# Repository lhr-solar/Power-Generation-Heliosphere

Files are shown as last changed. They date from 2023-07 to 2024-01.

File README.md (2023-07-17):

# :sunny: Heliosphere - Lighting automation control jig.

- [:sunny: Heliosphere - Lighting automation control jig.](#sunny-heliosphere---lighting-automation-control-jig)
  - [Repository Structure](#repository-structure)
  - [Maintainers](#maintainers)
  - [Versioning](#versioning)
  - [TODO](#todo)
    - [Documentation](#documentation)
    - [HW](#hw)
    - [SW](#sw)

---

## Repository Structure

- **datasheets** - contains datasheets for major components of the PCB.
- **docs** - contains documentation on how to build, test, and use the PCB.
- **fw** - contains fw that is loaded onto the PCB.
  - **tests** - test programs used to characterize and validate the PCB.
  - **src** - main program used to run the PCB.
  - **inc** - internally developed libraries specific for the PCB.
  - **lib** - third party libraries used by the PCB.
- **hw**
  - **footprints** - project specfic footprint association files for the PCB.
  - **models** - 3d .step files for the PCB 3d viewer.
  - **symbols** - project specific symbol files for the PCB.
  - **vX.Y.Z** - frozen versioning folder for PCB production files.
  - design files

---

## Maintainers

The current maintainer of this project is Matthew Yu as of 07/16/2023. His email
is [matthewjkyu@gmail.com](matthewjkyu@gmail.com).

Special thanks to Professor Gary Hallock, who supervised the development and
design of this project.

---

## Versioning

This PCB is on unified version `0.1.0`. Every time the schematic and/or layout
is updated, this version number should go up. We use [semantic
versioning](https://semver.org/) to denote between versions. See the
[changelog](./docs/CHANGELOG.md) for more details.

---

## TODO

### Documentation

- Update the following documents:
  - [Ordering and assembly](./docs/ORDERING_AND_ASSEMBLY.md)
  - [Testing](./docs/TESTING.md)
- Add datasheets for key components of the device.

### HW

- See [changelog 0.2.0rc](./docs/CHANGELOG.md#020rc-proposed) proposed changes to improve board cost, size.

### SW

- Regenerate code for MBED with proposed file structure.

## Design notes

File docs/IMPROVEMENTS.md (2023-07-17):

# IMPROVEMENTS

- [IMPROVEMENTS](#improvements)
  - [Digital PWM control](#digital-pwm-control)

---

## Digital PWM control

After verifying that v0.1.0 works with analog trimpots, the next step would be
using a digital PWM controller to control brightness. This is useful in a couple
ways:

- Removes dependency on Dale trimpots, which don't appear to exist anymore
  outside of Hallock's lab
- The trimpots are large, which restricts the lighting density and therefore the
  maximum uniform irradiance incident upon the surface (e.g. farther the
  spacing, the more vertical distance required for even spread). Switching to a
  SOT-23-3 or similar package MOSFET hooked up to a controller reduces the size
  restriction drastically. Ideally we can get back to 40x40 mm instead of 50x50 mm.
- The digital control enables automagic feedback control. Hook up to the PV
  Curve Tracer and the Blackbody B, and then we can automatically tune segment
  brightness as well as emulate various PVEnvironment regimes that are only
  usable in Eclipse simulation.

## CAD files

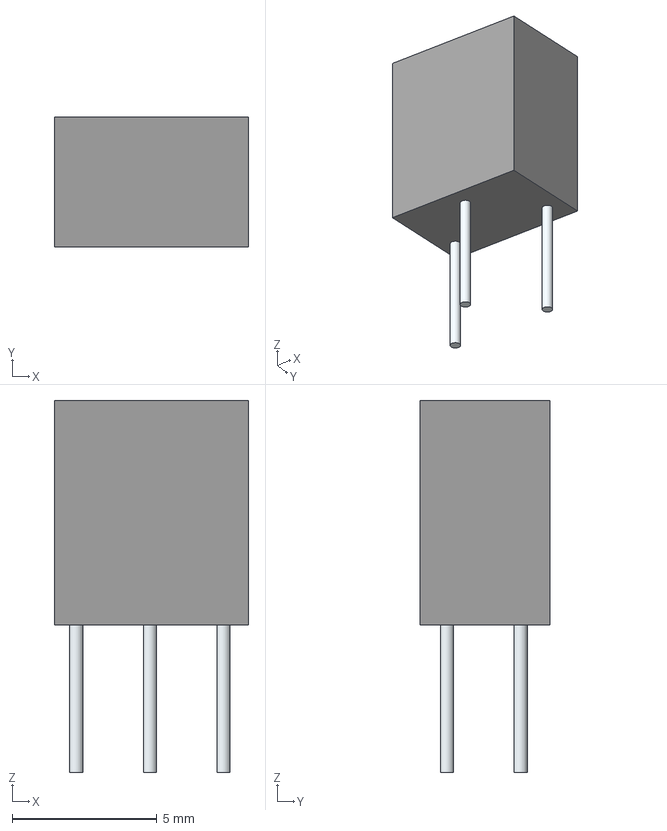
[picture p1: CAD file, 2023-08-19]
hw/models/bourns_3266W_1_200LF.stp
6.71 x 4.50 x 12.8 mm
Leads

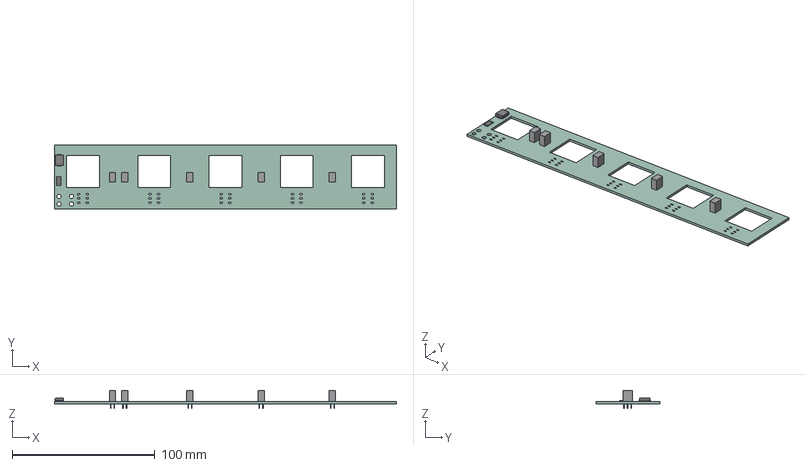
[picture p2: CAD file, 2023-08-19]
hw/v0.1.0/heliosphere.step
240.0 x 45.0 x 12.8 mm
_autosave-heliosphere PCB

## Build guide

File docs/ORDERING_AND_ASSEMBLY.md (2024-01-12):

# ORDERING AND ASSEMBLY

## Ordering

- Generate gerbers using JLC PCB fabrication toolkit (1 button click).
- Navigate to JLCPCB site and upload zip file provided.
- No assembly is performed for this PCB. Order as default FR4, 2 layer.

## Assembly

Use the ibom.html provided in the outputs file for placement.

- Solder R101 to PCB.
  - Solder one side before other. Keep package flat against PCB.
- Solder D106 to PCB.
  - Marking side is the cathode (positive). Solder closest to enclosed line on silkscreen.
  - Solder one side before other. Keep package flat against PCB.
- Solder VR101 - VR105 to PCB.
  - Place on PCB, hold, flip PCB, bend legs outwards to keep in place.
- Solder D101 - D105 to PCB.
  - Tin surfaces of pads, both on PCB and LED package. Keep flat.
  - Use masking tape to hold package to bottom side, facing down. Align with silkscreen.
  - With a soldering iron, solder from top of PCB into holes. Make sure
    soldering tip can reach the package. Hold firm to each other. Fill hole with
    solder. Hold long enough that solder wicks down to PCB pad. A negative
    indent is good.
  - Verify that the pieces are soldered down properly and flush. Gaps require
    resoldering and will likely not light up during testing.
- Solder AWG 18 wires to positive, negative contacts indicated on silkscreen.

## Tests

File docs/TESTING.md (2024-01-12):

# TESTING

1. Ensure that diode is placed correctly using multimeter. Should short from GND to PWR.
2. Use a power supply at >=10V, 0.5A to power the board. LEDs should turn on.
3. Lights should dim or brighten based on turns of trimpots.
   1. Right turns increase resistance. Left turns decrease resistance.
4. Use the Blackbody B to measure the irradiance uniformity of every light in a
   dark room. Place the board while running under the centerpoint of each light.
   Measure the light and adjust the resistance of the trimpot to gradually align
   all measurements to a single value.

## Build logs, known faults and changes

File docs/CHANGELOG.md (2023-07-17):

# CHANGELOG

- [CHANGELOG](#changelog)
  - [0.1.0](#010)
  - [0.2.0rc (proposed)](#020rc-proposed)

---

## 0.1.0

Initial version.

## 0.2.0rc (proposed)

**Schematic**

- Switch from manual analog control via rotary potentiometers to digital control via PWM.

**Layout**

- Optimize layout.

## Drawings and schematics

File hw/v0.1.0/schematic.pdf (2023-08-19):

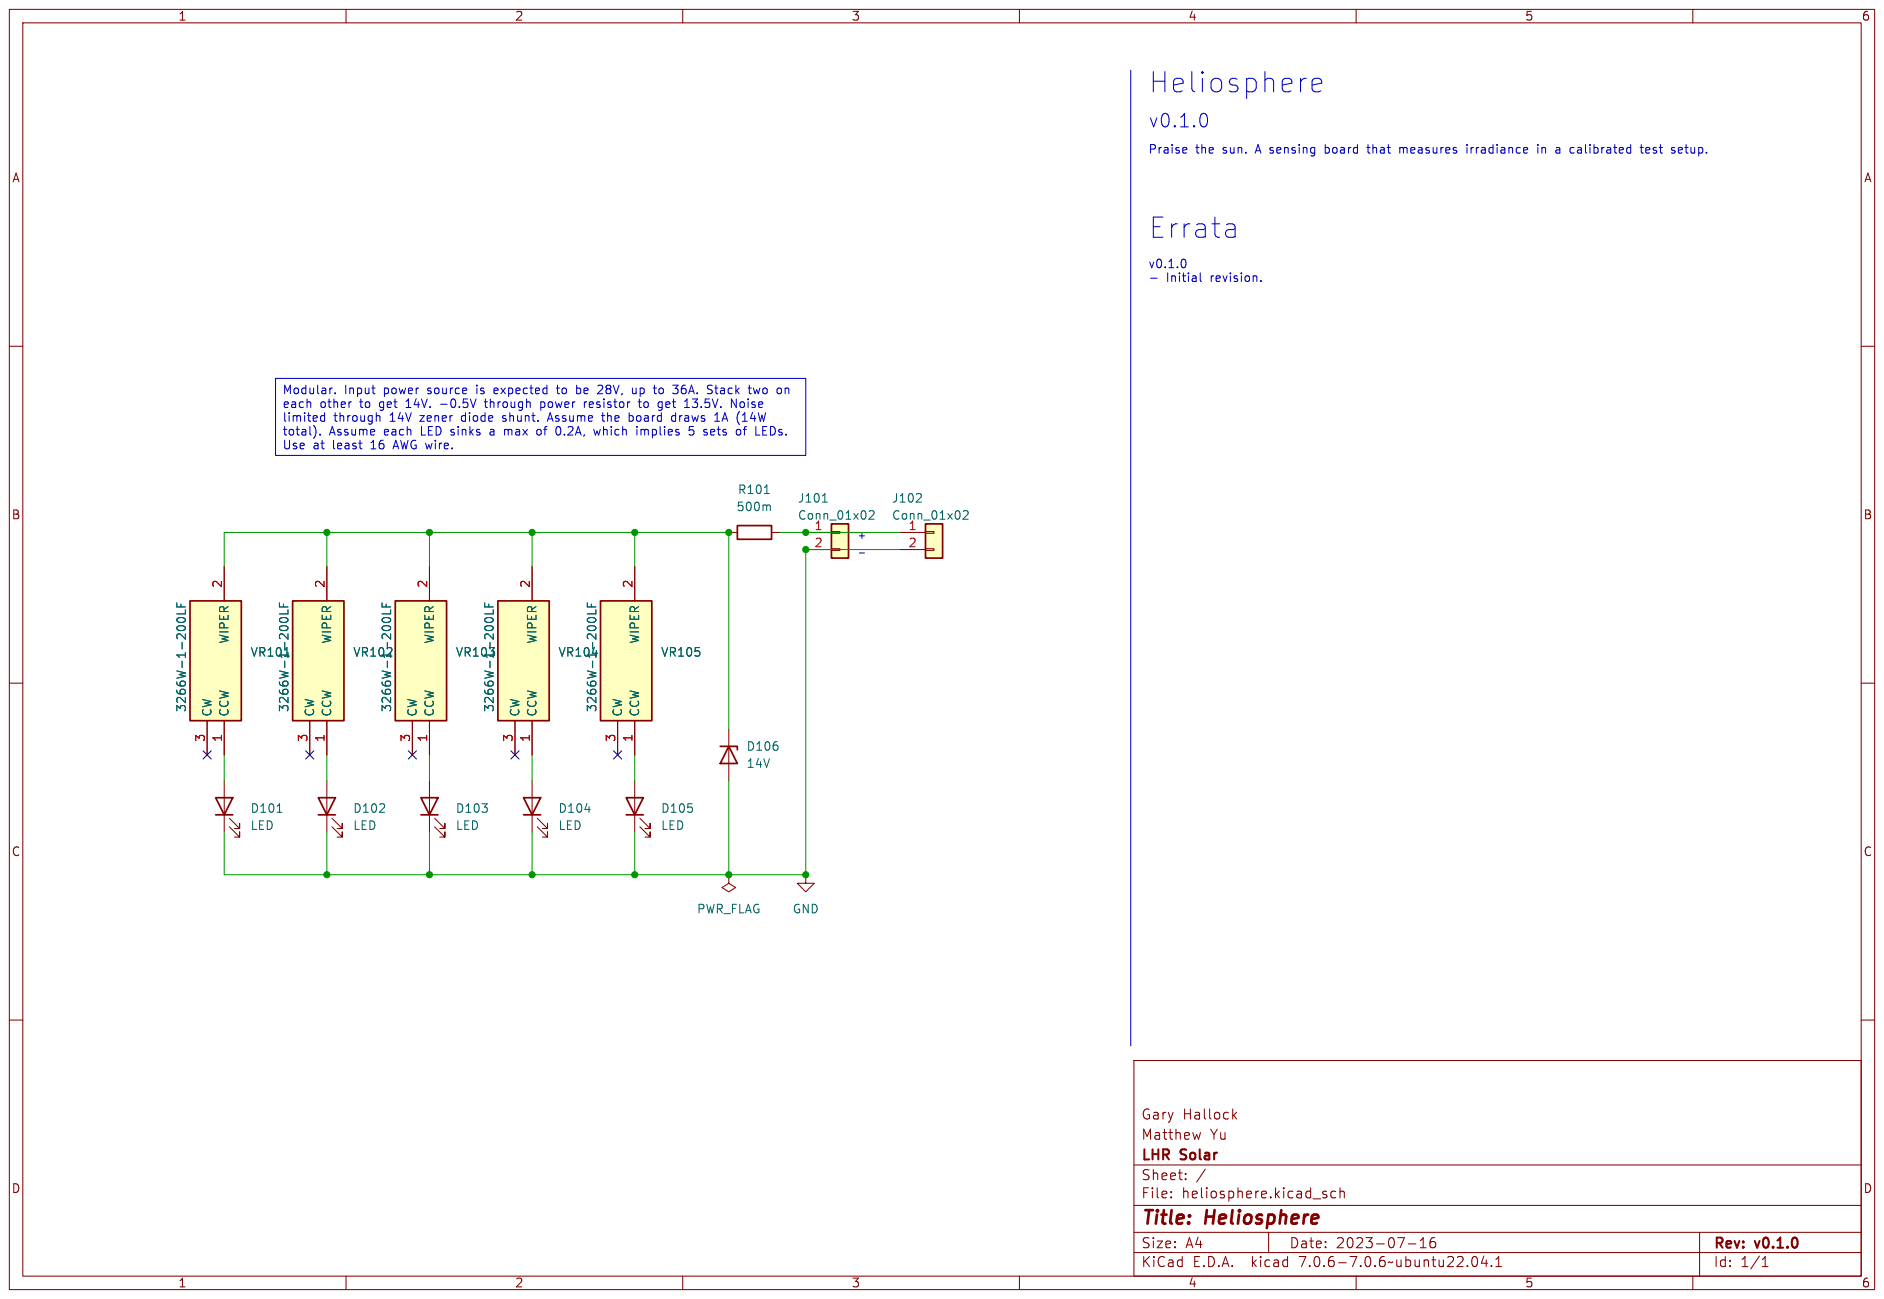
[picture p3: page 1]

Modular. Input power source is expected to be 28V, up to 36A. Stack two on

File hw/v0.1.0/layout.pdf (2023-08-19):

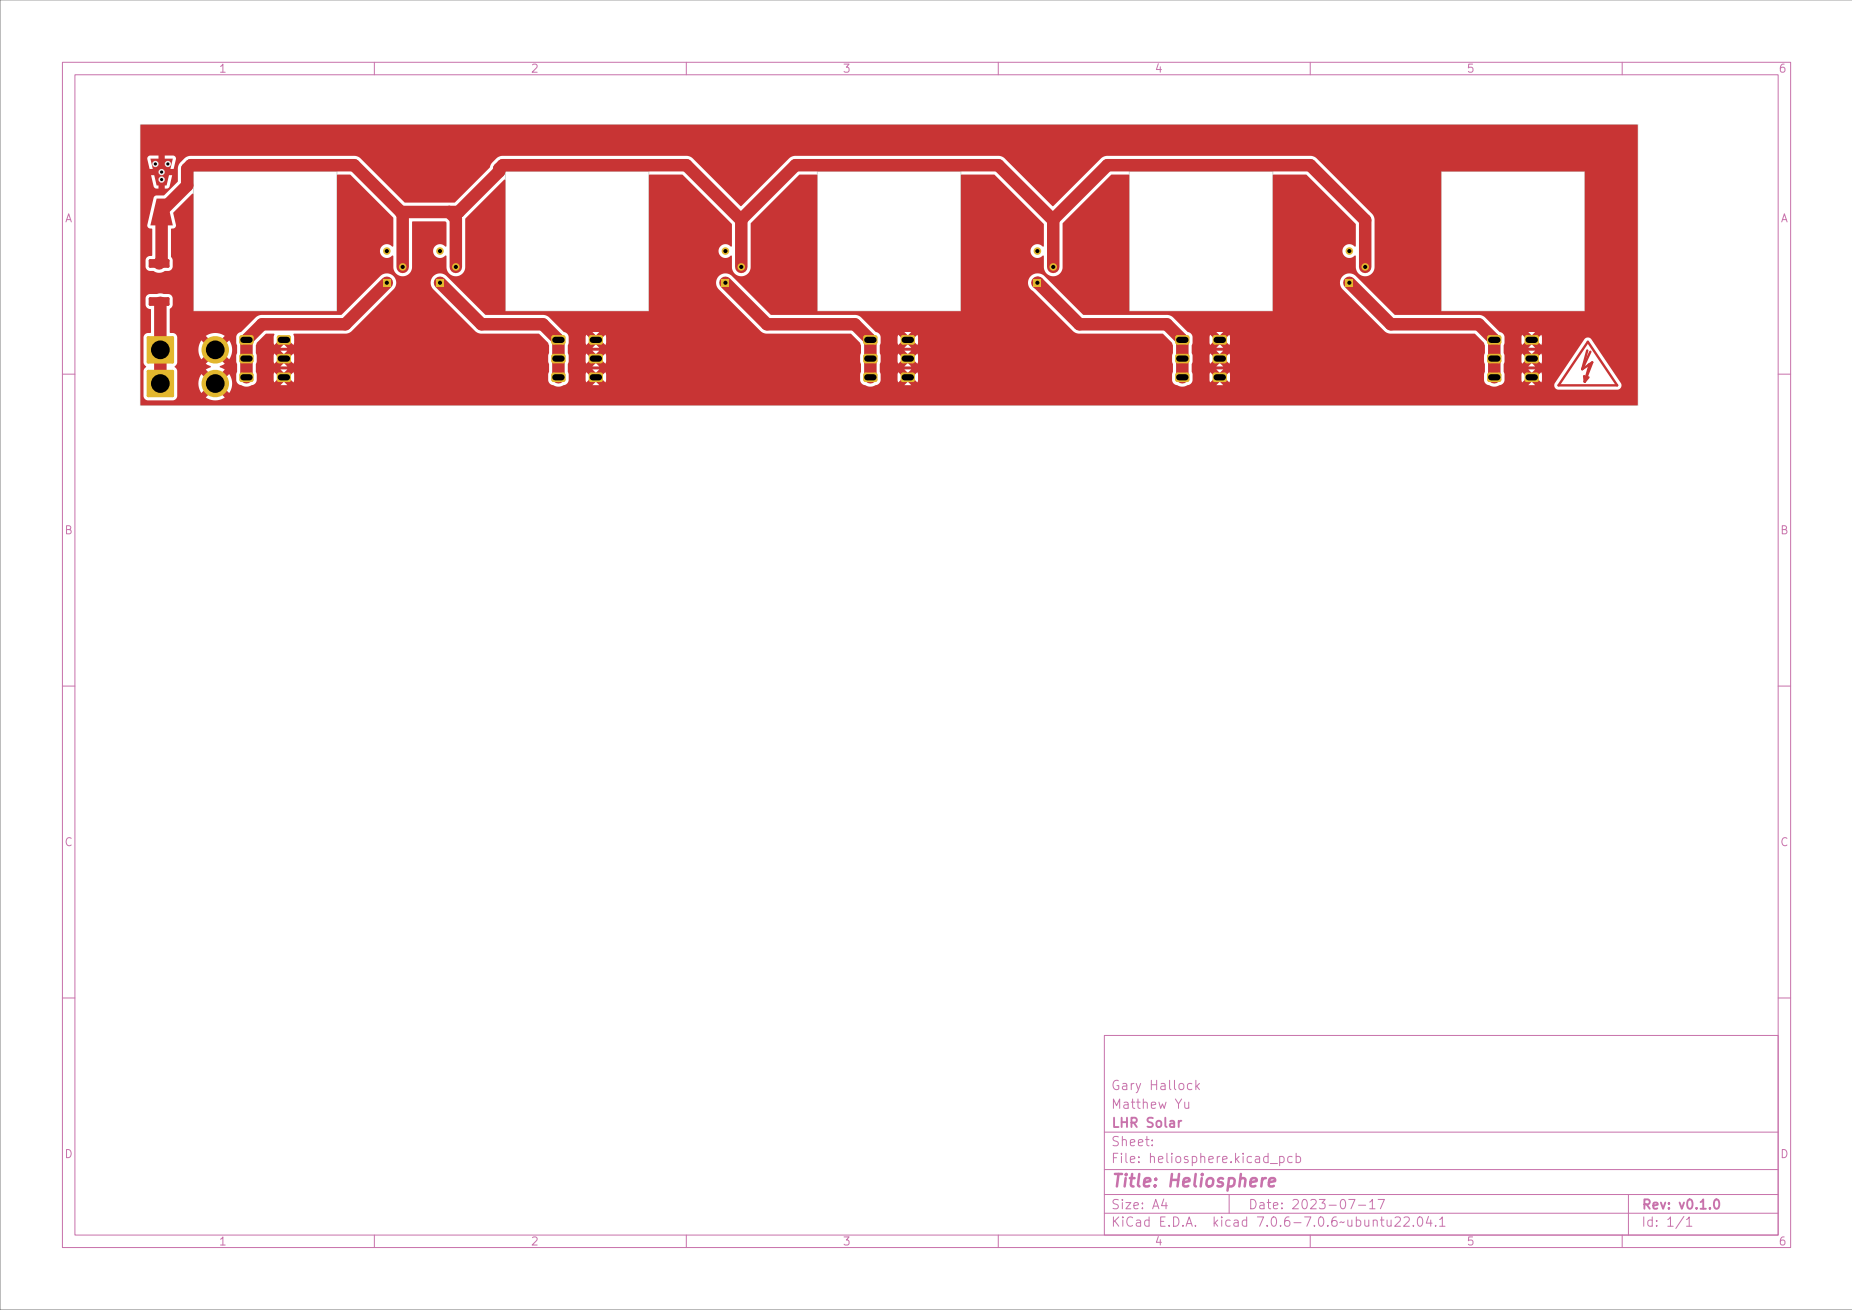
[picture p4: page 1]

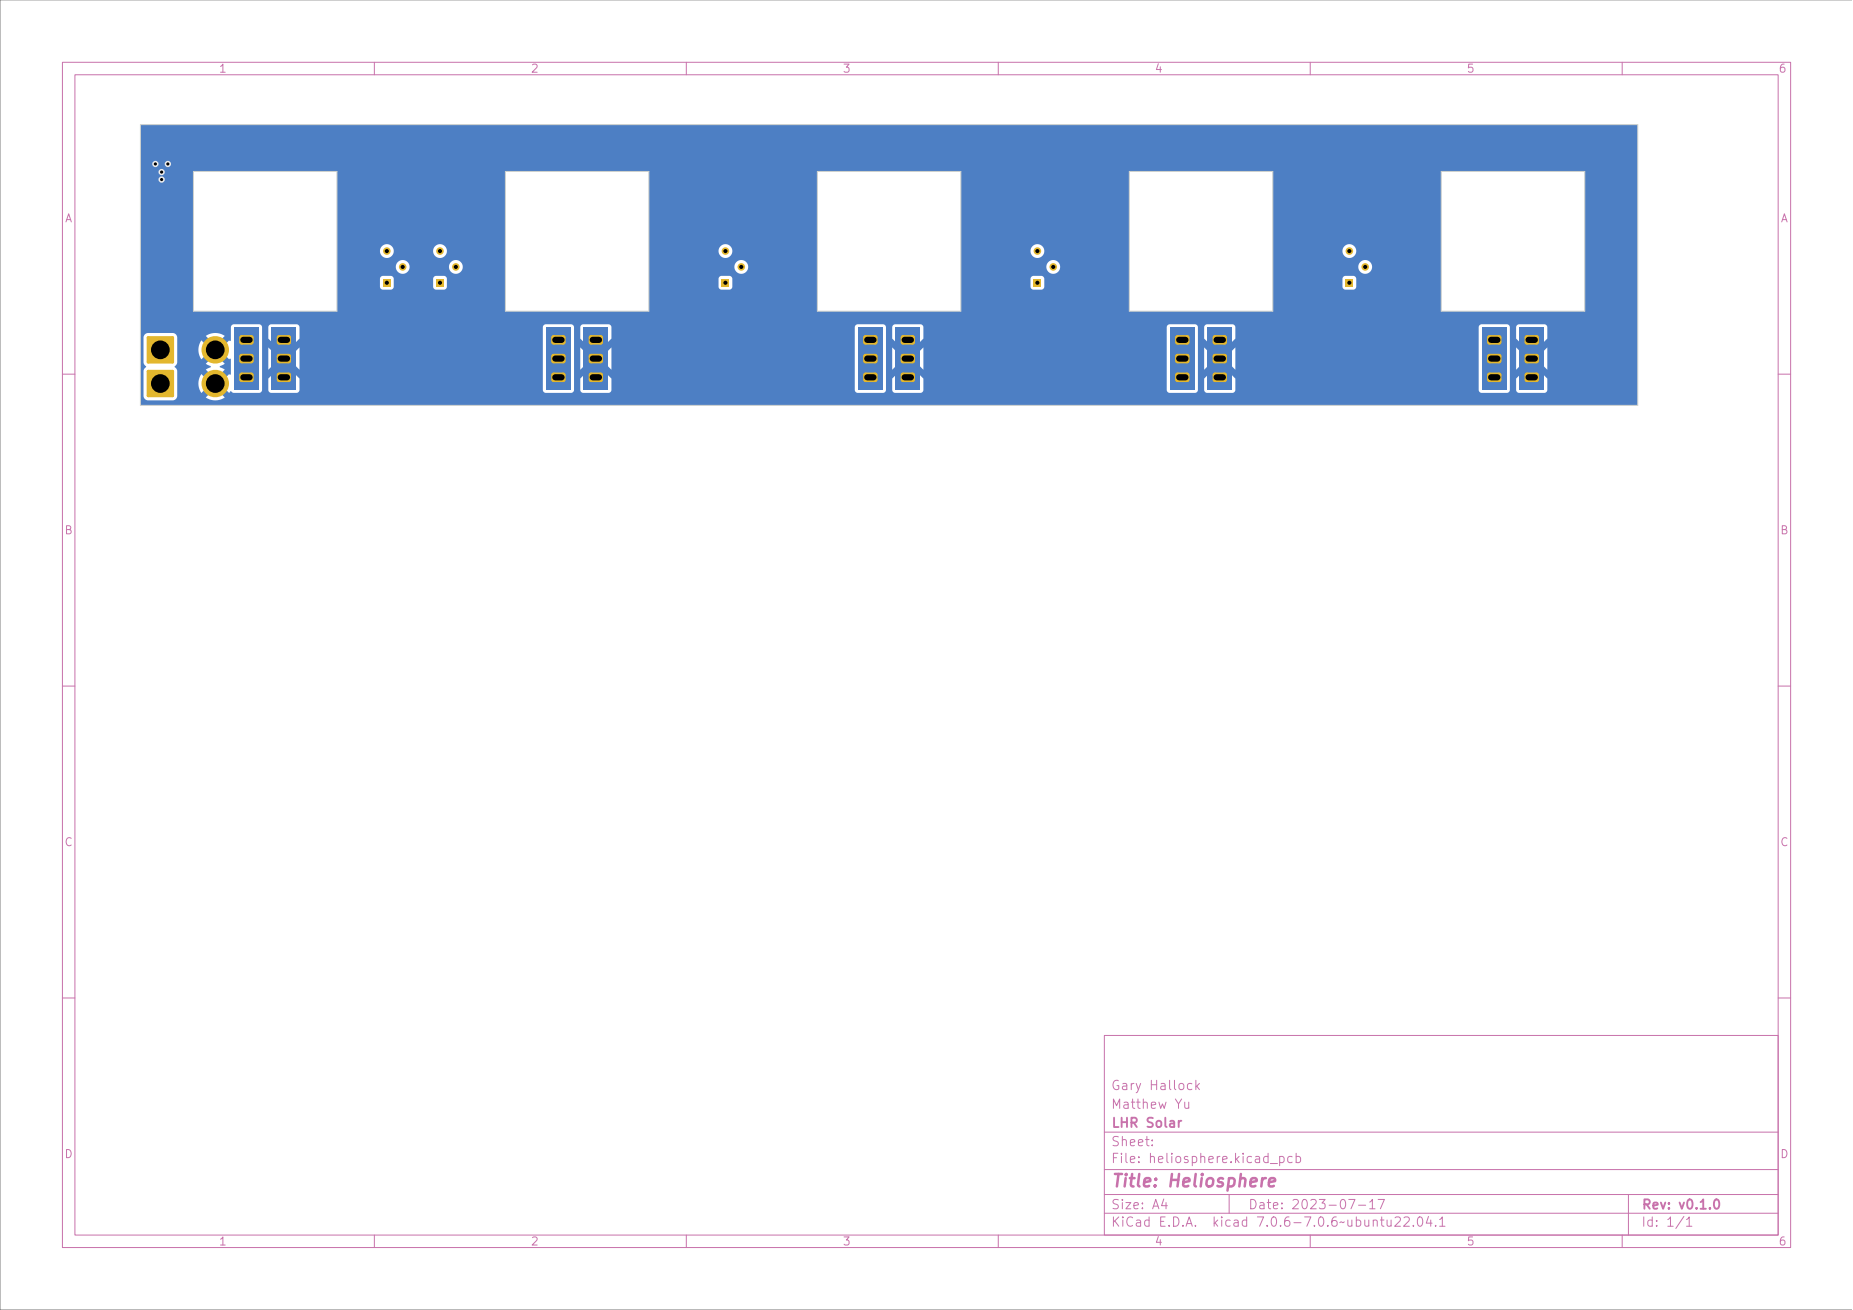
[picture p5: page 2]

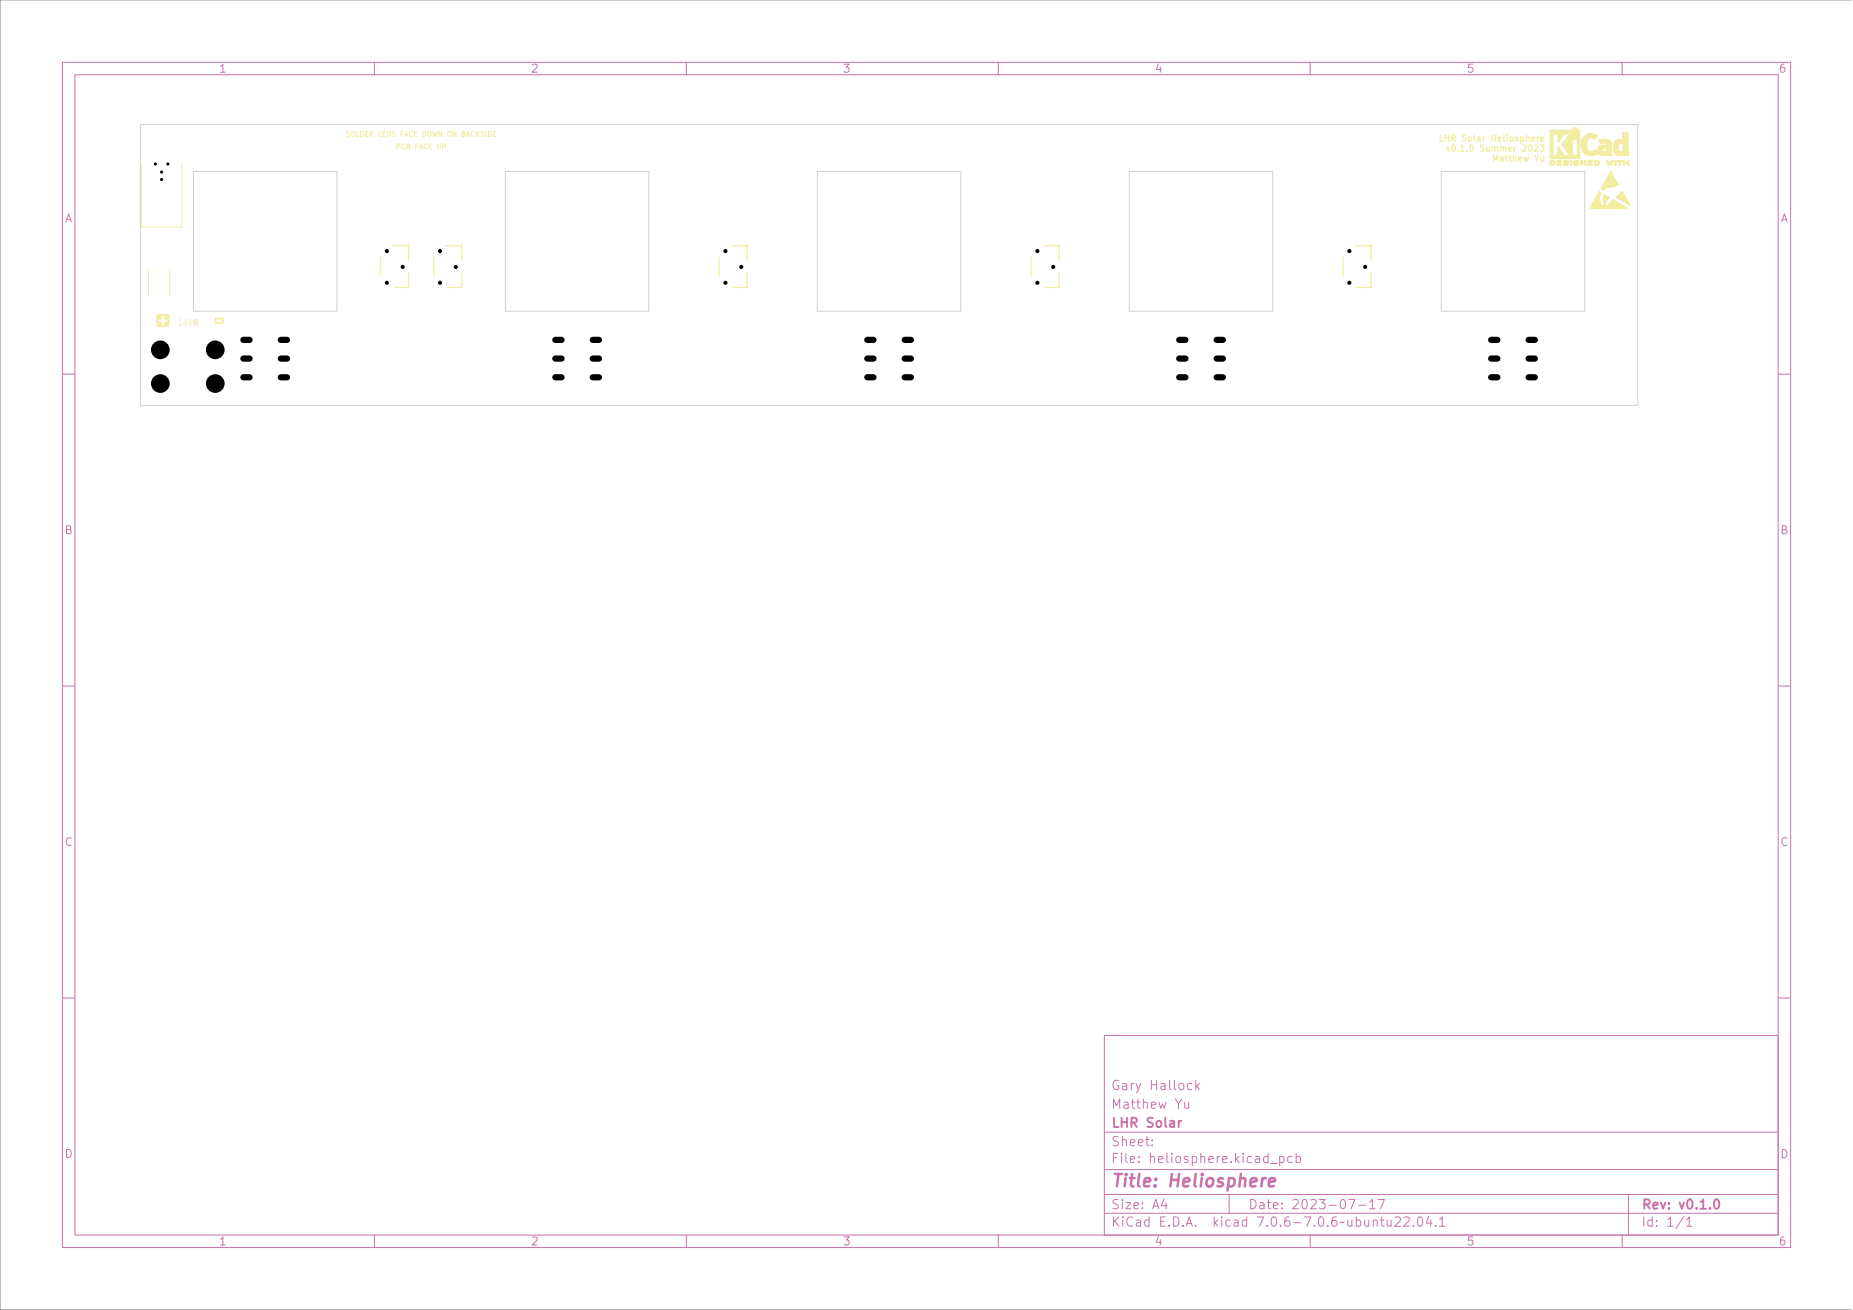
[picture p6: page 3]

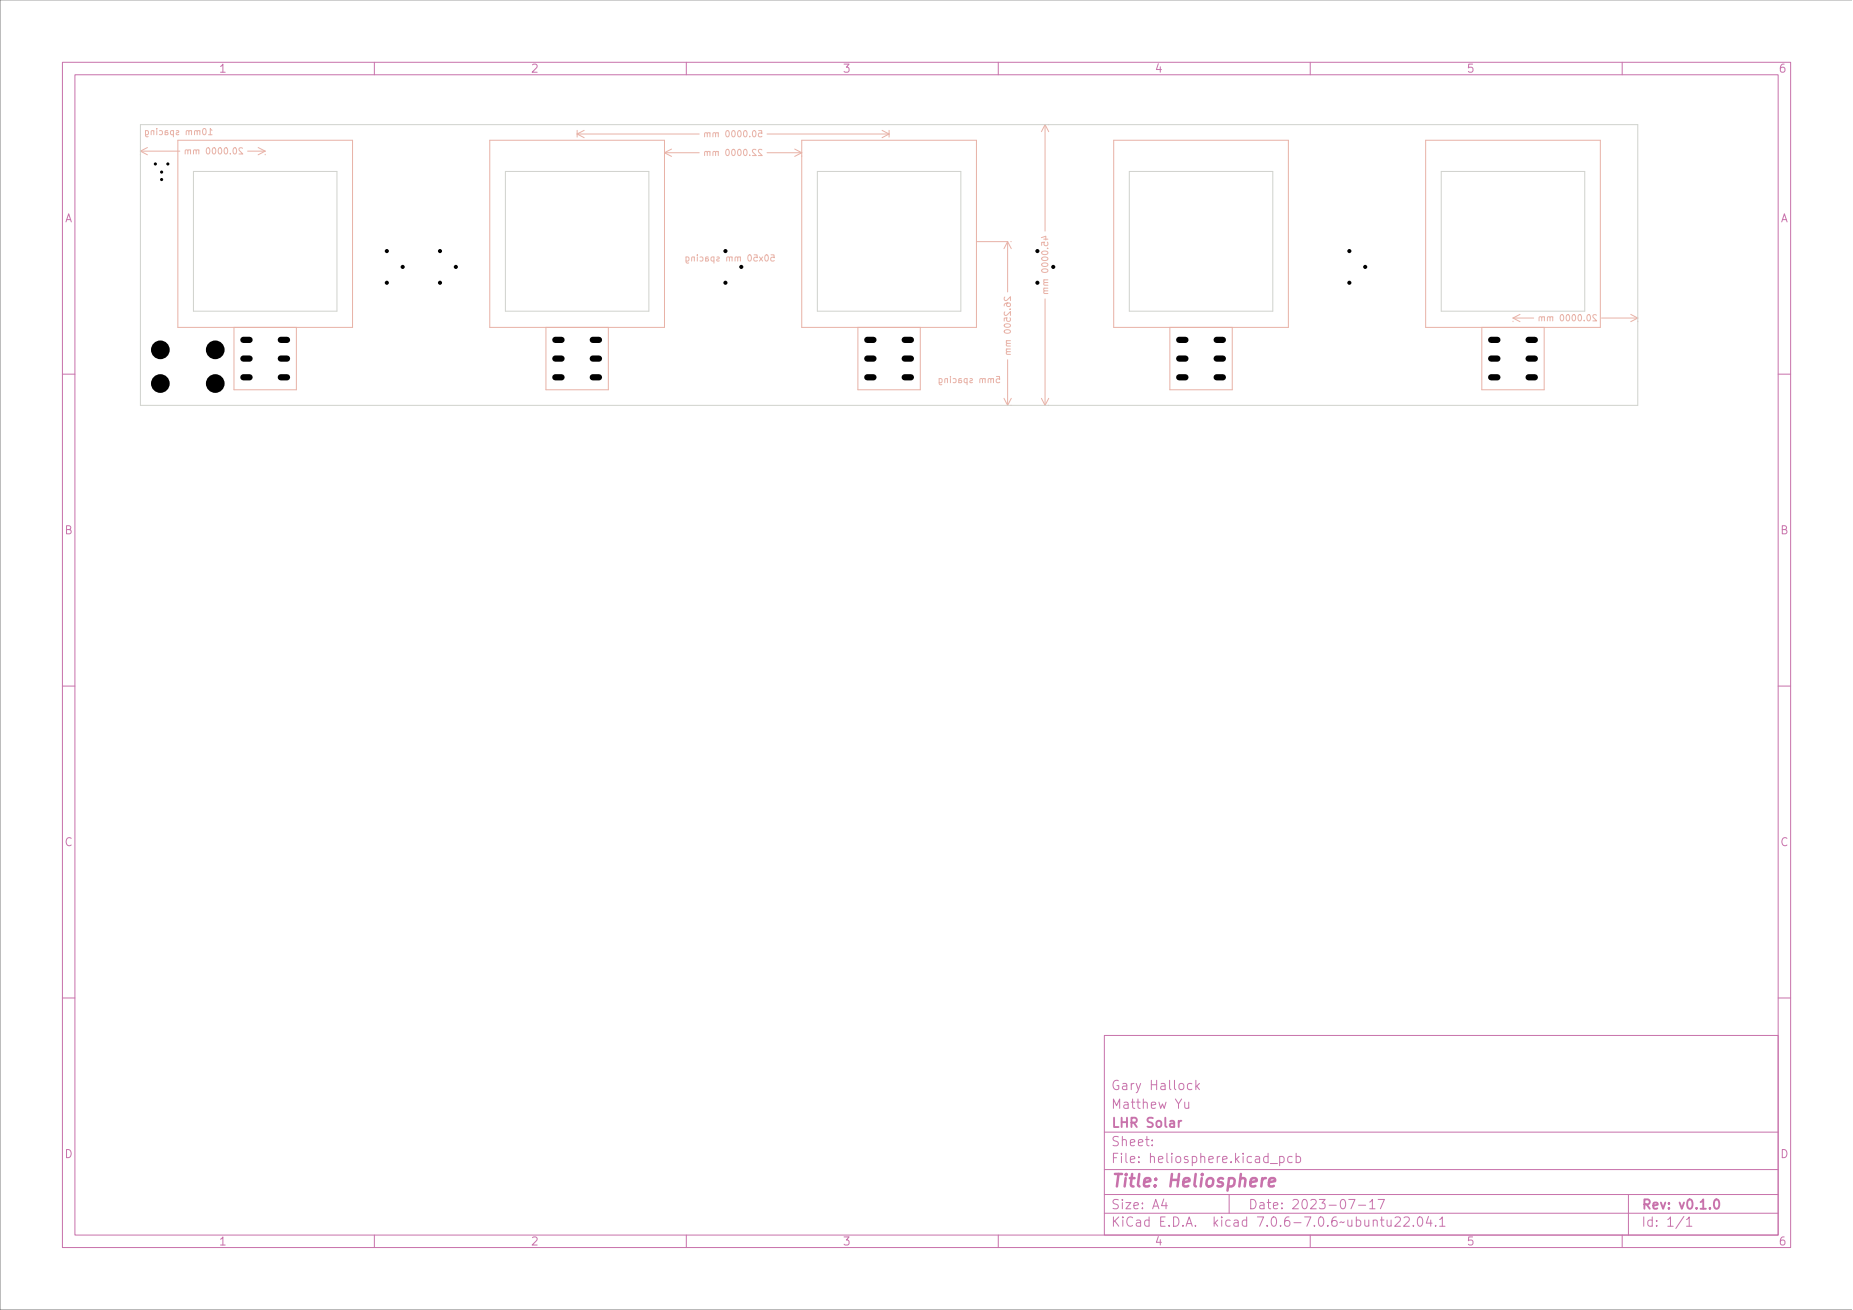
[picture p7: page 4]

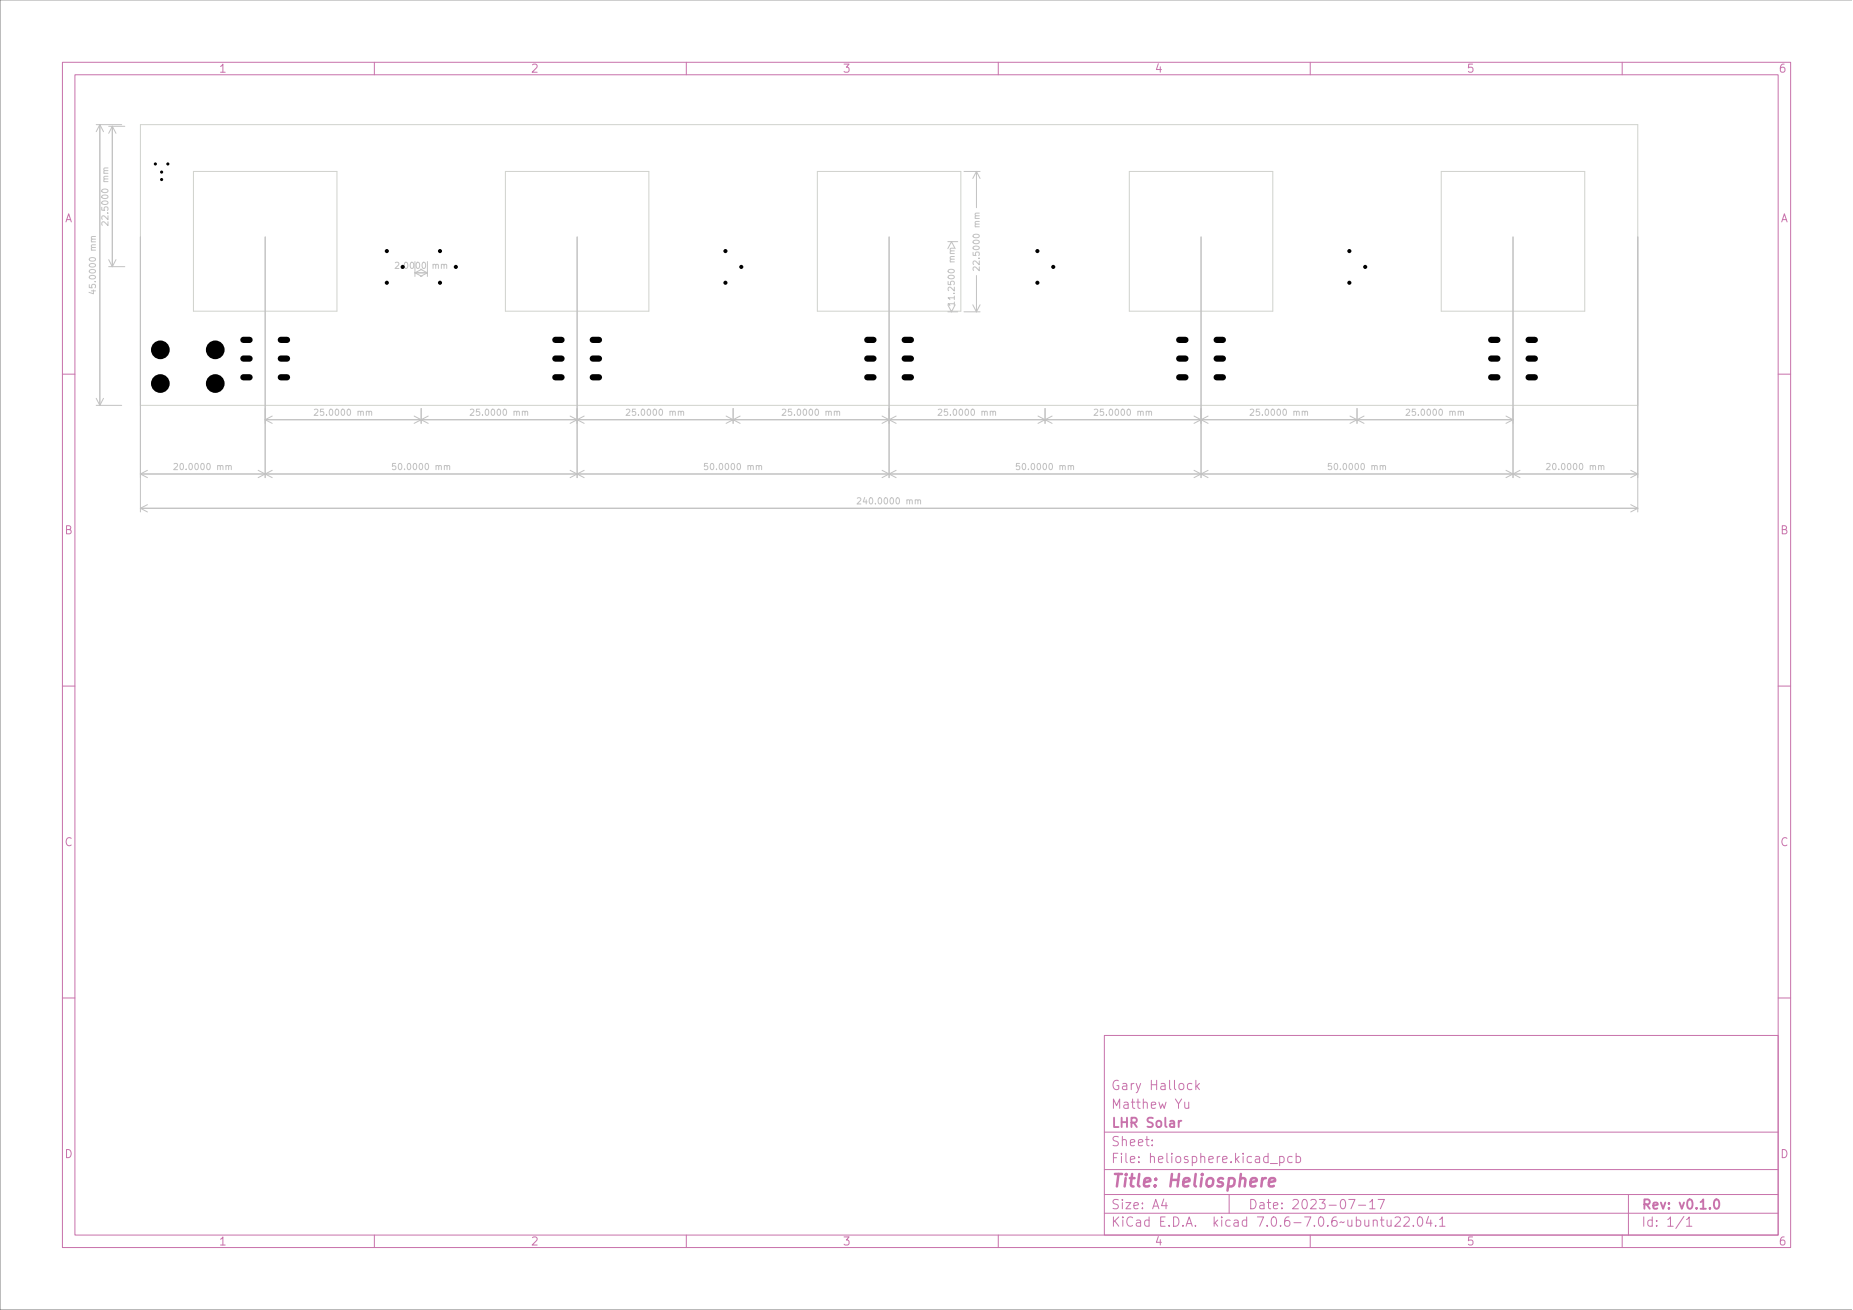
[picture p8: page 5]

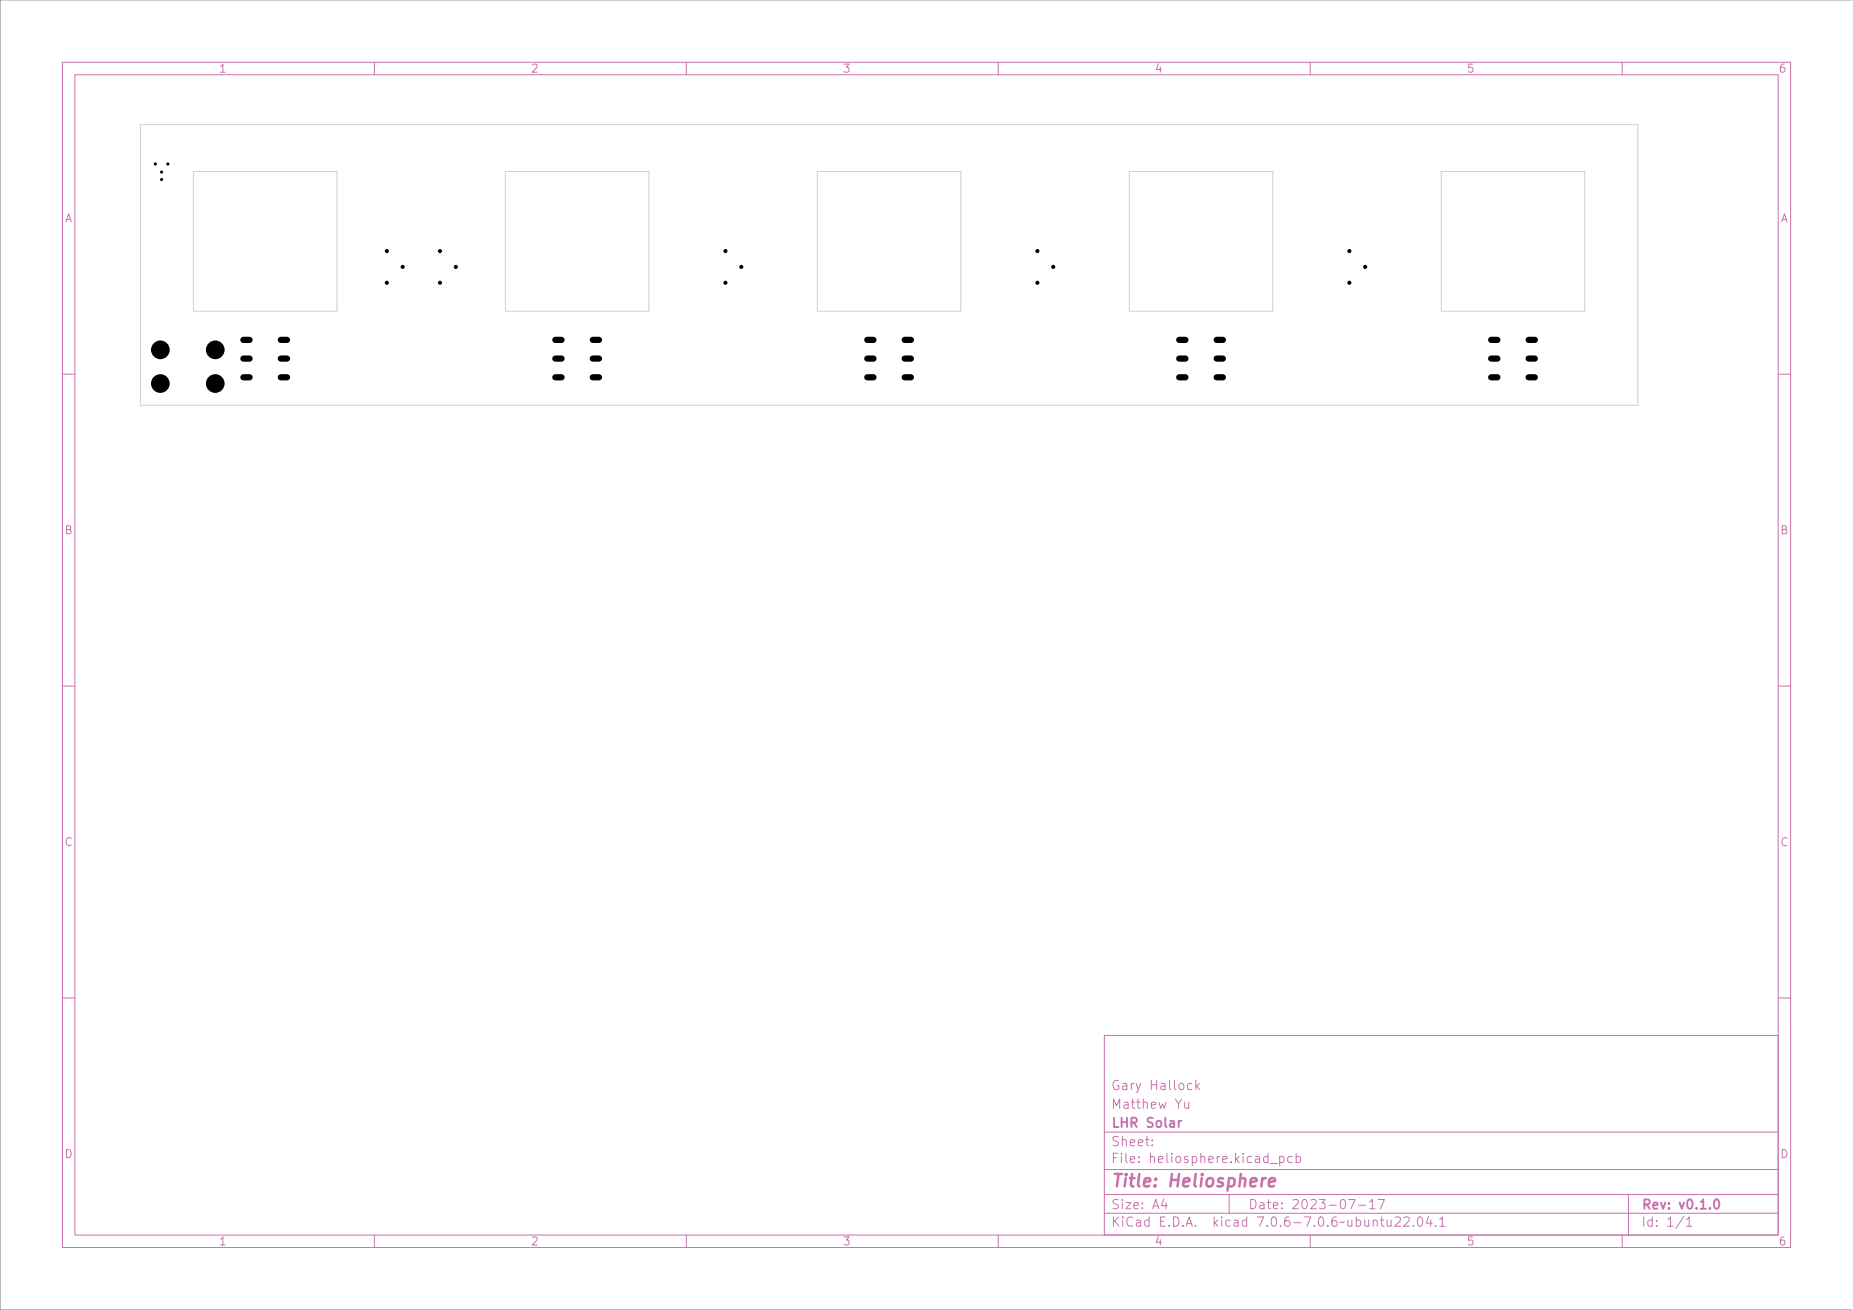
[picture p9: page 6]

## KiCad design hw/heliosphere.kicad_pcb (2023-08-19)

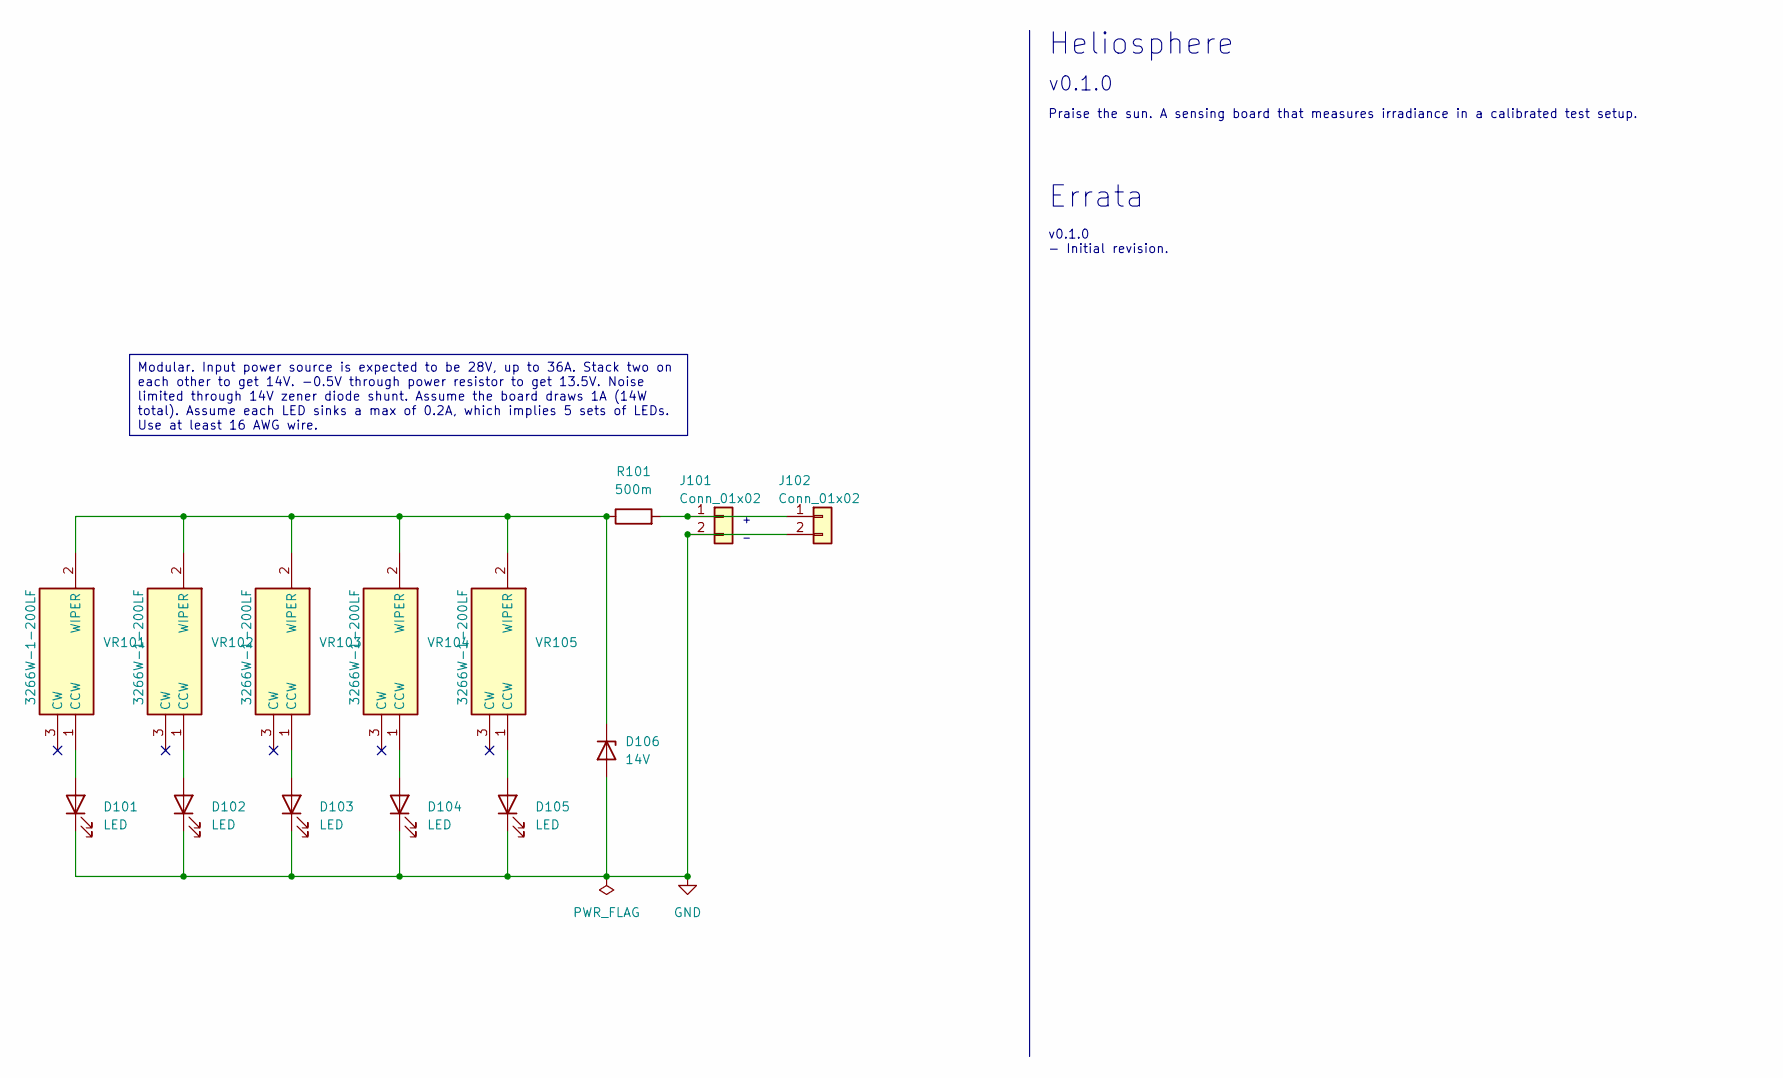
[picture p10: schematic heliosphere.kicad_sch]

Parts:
D101, D102, D103, D104, D105: LED; xishwon_led_bulb
D106: 14V; D_SMB-SMC_Universal_Handsoldering
J101, J102: Conn_01x02; SolderWire-2.5sqmm_1x02_P8.8mm_D2.4mm_OD4.4mm
R101: 500m; R_2512_6332Metric_Pad1.40x3.35mm_HandSolder
VR101, VR102, VR103, VR104, VR105: 3266W-1-200LF; bourns3266W_1_200LF

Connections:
GND: D101.1 (K), D102.1 (K), D103.1 (K), D104.1 (K), D105.1 (K), D106.2 (A), J101.2, J102.2
unnamed: D101.2 (A), VR101.1 (CCW)
unnamed: D102.2 (A), VR102.1 (CCW)
unnamed: D103.2 (A), VR103.1 (CCW)
unnamed: D104.2 (A), VR104.1 (CCW)
unnamed: D105.2 (A), VR105.1 (CCW)
unnamed: D106.1 (K), R101.1, VR101.2 (WIPER), VR102.2 (WIPER), VR103.2 (WIPER), VR104.2 (WIPER), VR105.2 (WIPER)
unnamed: J101.1, J102.1, R101.2

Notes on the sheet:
Modular. Input power source is expected to be 28V, up to 36A. Stack two on each other to get 14V. -0.5V through power resistor to get 13.5V. Noise limited through 14V zener diode shunt. Assume the board draws 1A (14W total). Assume each LED sinks a max of 0.2A, which implies 5 sets of LEDs. Use at 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
Heliosphere
Errata
v0.1.0 - Initial revision.
Praise the sun. A sensing board that measures irradiance in a calibrated test setup.
v0.1.0

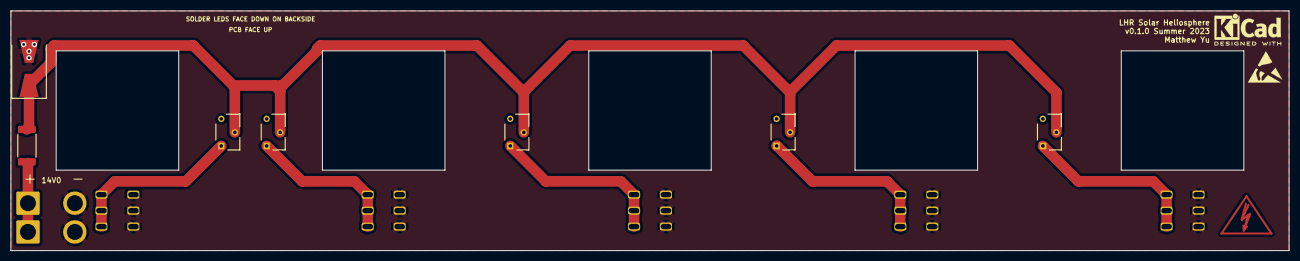
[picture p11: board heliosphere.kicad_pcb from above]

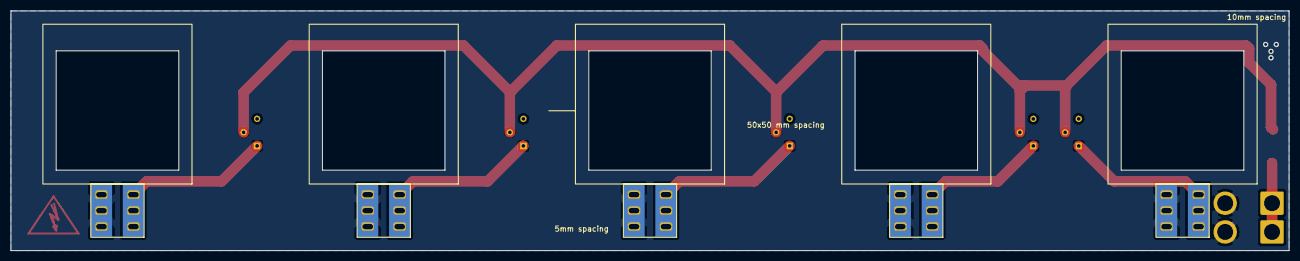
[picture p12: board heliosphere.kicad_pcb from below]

Board: 2 copper layers, 240.0 x 45.0 mm, 14 parts (5 on the bottom side), 8 nets.

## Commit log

2023-07-17 init commit for v0.1.0 of heliosphere.
    [heliosphere.kicad_pcb, heliosphere.kicad_sch, heliosphere.step]
2023-08-01 footprint and schematic update
    [heliosphere.kicad_pcb, heliosphere.kicad_sch, heliosphere.step]
2023-08-19 swap trimpot for available one on mouser
    [bourns_3266W_1_200LF.stp, heliosphere.kicad_pcb, heliosphere.kicad_sch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]
